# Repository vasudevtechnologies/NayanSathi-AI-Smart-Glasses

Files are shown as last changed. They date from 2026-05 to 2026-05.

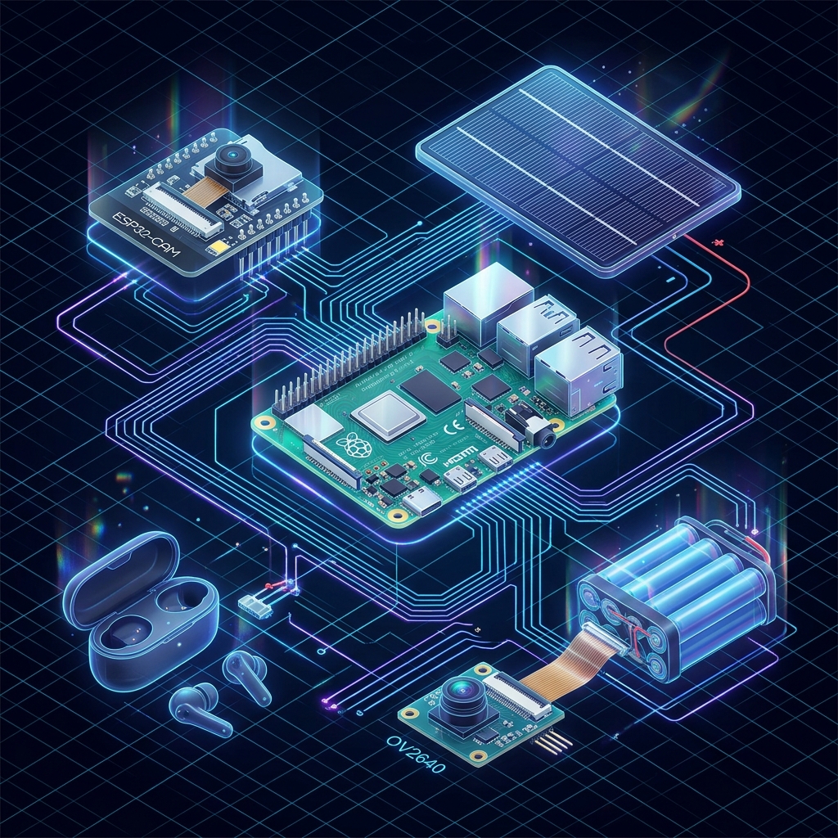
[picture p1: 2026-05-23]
website/images/hardware-diagram.png

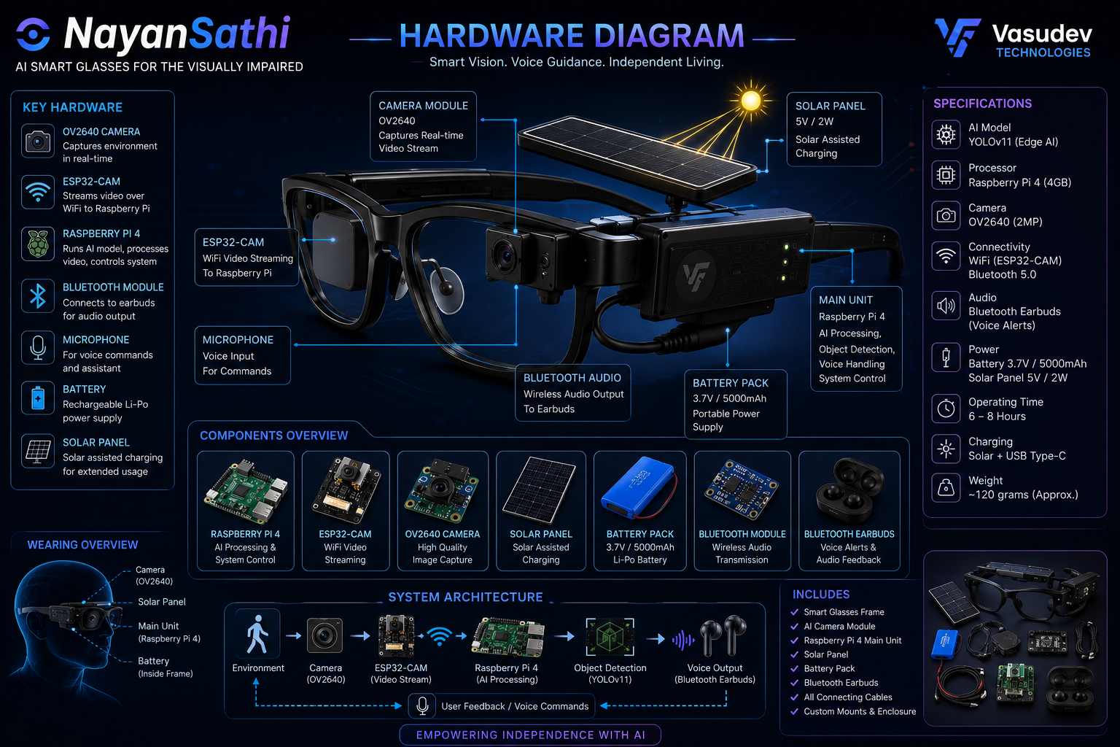
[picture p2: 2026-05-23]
Hardware/Hardware.png

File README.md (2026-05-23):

# NayanSathi-AI-Smart-Glasses
🕶️ NayanSathi — AI Smart Glasses for the Visually Impaired NayanSathi is an AI-powered wearable assistive system designed to help visually impaired individuals navigate and understand their surroundings in real time. Built using Raspberry Pi 4, ESP32-CAM, YOLOv11, and Edge AI technologies, the smart glasses detect nearby objects

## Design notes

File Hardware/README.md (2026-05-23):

# 🔧 Hardware

This folder contains all hardware-related files for **NayanSathi — AI Smart Glasses**.

## Contents
- Component datasheets (Raspberry Pi 4, ESP32-CAM, TP4056, etc.)
- Wiring diagrams
- 3D model files for glasses frame (.stl, .step)
- Bill of Materials (BOM)
- Assembly instructions
- Solar panel integration guide

## Bill of Materials (BOM)

| Component | Model | Specification | Cost (INR) |
|---|---|---|---|
| Raspberry Pi 4 | 4GB RAM | Quad-core ARM Cortex-A72 | Rs. 5,500 |
| ESP32-CAM | OV2640 | 2MP, Wi-Fi, MJPEG stream | Rs. 350 |
| Bluetooth Earbuds | boAt Airdopes 141 | A2DP, Bluetooth 5.0 | Rs. 700 |
| Li-Po Battery | 3000mAh 3.7V | Rechargeable, compact | Rs. 450 |
| Solar Panel | 5V / 1W Flexible | Magnetic clip-on design | Rs. 350 |
| TP4056 Module | Charge Controller | Overcharge protection | Rs. 30 |
| MT3608 Boost | 5V Boost Converter | 3.7V to 5V | Rs. 50 |
| 3D Printed Frame | Custom Design | PLA, glasses form factor | Rs. 400 |
| Custom PCB | KiCad Designed | ESP32 + Power circuit | Rs. 200 |
| MicroSD Card | 32GB Class 10 | OS + model storage | Rs. 200 |
| Misc (wires, etc.) | — | Jumper wires, resistors | Rs. 100 |
| **TOTAL** | | | **~Rs. 8,330** |

## Solar Panel Design
- **Attachment:** Magnetic pogo-pin connectors on glasses top bar
- **Daytime:** Snap-on → charges Li-Po via TP4056 (~100–200mA)
- **Nighttime:** Snap-off in 1 second — lightweight, no tools needed
- **Added weight:** ~20g when attached

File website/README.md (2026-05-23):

# NayanSathi — Website Deployment Guide

> 🚀 Futuristic AI Startup showcase website for NayanSathi

## 📁 Folder Structure

```
website/
├── index.html          ← Main website (all CSS + JS embedded)
├── vercel.json         ← Vercel deployment config
├── images/
│   ├── hero.png                ← AI Smart Glasses hero image (exploded view)
│   ├── product-showcase.png    ← Product showcase with key specs
│   ├── hardware-diagram.png    ← Full hardware diagram
│   ├── circuit-diagram.png     ← Complete circuit/wiring diagram
│   └── day-night.png           ← Day & Night mode comparison
└── README.md
```

## 🖼️ Adding Your Images

Copy your 5 project images into the `images/` folder with EXACTLY these filenames:

| Filename | Description |
|---|---|
| `hero.png` | The NayanSathi AI glasses exploded holographic render |
| `product-showcase.png` | Product showcase with specs on the right |
| `hardware-diagram.png` | Full hardware component diagram |
| `circuit-diagram.png` | Complete circuit / wiring diagram |
| `day-night.png` | Day mode vs Night mode comparison |

## 🌐 Deploy to Vercel

### Method 1: Vercel CLI (Recommended)
```bash
# Install Vercel CLI
npm install -g vercel

# Navigate to website folder
cd website/

# Deploy
vercel --prod
```

### Method 2: Vercel Dashboard (Easiest)
1. Go to [vercel.com](https://vercel.com)
2. Click **Add New → Project**
3. Import from GitHub: `vasudevtechnologies/NayanSathi-AI-Smart-Glasses`
4. Set **Root Directory** to `website`
5. Click **Deploy** ✅

### Method 3: Drag & Drop
1. Go to [vercel.com/new](https://vercel.com/new)
2. Drag the entire `website/` folder into Vercel
3. Done!

## ✅ Website Sections

- 🎬 **Hero** — Cinematic hero with live HUD stats
- ✨ **Features** — 9 feature cards with glow hover effects
- 🖼️ **Product Showcase** — Full-width product image + specs
- 🔄 **System Architecture** — Animated flow diagram
- 🔧 **Hardware Diagram** — Your actual hardware image
- 📊 **Live Dashboard** — Animated fake dashboard with canvas cam feed
- 🌙 **Day/Night Mode** — Power system showcase
- ⚡ **Circuit Diagram** — Full wiring schematic  
- 🔮 **Future Scope** — 6 roadmap cards
- 🏢 **About** — Vasudev Technologies branding
- 🦶 **Footer** — Links, social, copyright

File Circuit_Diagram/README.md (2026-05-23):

# ⚡ Circuit_Diagram

This folder contains all circuit schematics and PCB design files for **NayanSathi — AI Smart Glasses**.

## Contents
- `esp32_multi_sensor.kicad_pcb` — Main KiCad PCB design
- `schematic.pdf` — Printable full circuit schematic
- `wiring_diagram.png` — Complete wiring connection diagram
- `power_circuit.png` — Solar + battery power circuit
- `pcb_gerber/` — Gerber files for PCB manufacturing

## Power Circuit

```
☀️ Solar Panel (5V, 1W)
         │
         ▼
   ┌─────────────┐
   │   TP4056    │  ← Charge Controller (overcharge protected)
   │   Module    │
   └──────┬──────┘
          │
          ▼
   Li-Po Battery (3.7V, 3000mAh)
          │
          ▼
   ┌─────────────┐
   │   MT3608    │  ← Boost Converter (3.7V → 5V)
   │   Boost     │
   └──────┬──────┘
          │
     ┌────┴────┐
     ▼         ▼
Raspberry Pi 4  ESP32-CAM
  (USB-C 5V)   (5V Pin)
```

## Pin Connections

| From | Pin | To | Pin | Signal |
|---|---|---|---|---|
| ESP32-CAM | GPIO 1 (TX) | Raspberry Pi | GPIO 15 (RX) | UART |
| ESP32-CAM | 5V | MT3608 OUT | 5V | Power |
| ESP32-CAM | GND | Common GND | GND | Ground |
| Solar Panel | + | TP4056 | IN+ | 5V Solar Input |
| Solar Panel | - | TP4056 | IN- | Ground |
| TP4056 | BAT+ | Li-Po | + | Battery Charge |
| Li-Po | + | MT3608 | IN+ | 3.7V Input |
| MT3608 | OUT+ | Pi USB-C | + | 5V Output |
| Voltage Divider | OUT | Pi | GPIO ADC | Battery % |

## PCB Features (KiCad Design)
- ESP32-CAM mounting pads with castellated holes
- TP4056 solar charge controller footprint
- MT3608 boost converter section
- Voltage divider circuit (100kΩ + 100kΩ) for battery ADC monitoring
- I2C header (SDA/SCL) for optional IMU / barometer sensor
- Push button (GPIO 17) for mode switching
- 3x LED indicators: Power (Green), Bluetooth (Blue), Detection (Cyan)
- Magnetic pogo-pin pads for solar panel connector

## PCB Dimensions
- Size: ~45mm × 30mm (fits inside glasses frame)
- Layers: 2-layer PCB
- Thickness: 1.6mm standard FR4

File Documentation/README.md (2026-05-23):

# 📄 Documentation

This folder contains all project documentation for **NayanSathi — AI Smart Glasses**.

## Contents
- `Project_Report.pdf` — Full technical report
- `Abstract.pdf` — One-page project abstract
- `Presentation.pptx` — Slide deck for evaluation
- `User_Manual.pdf` — How to use the glasses
- `API_Docs.md` — REST API and WebSocket documentation
- `References.md` — Research papers and citations

## Project Abstract

**NayanSathi** ("Eye Companion") is an AI-powered wearable assistive device built as smart glasses for visually impaired individuals. Using a Raspberry Pi 4 + ESP32-CAM + YOLOv11n ONNX model, it provides real-time object detection with natural voice announcements delivered through Bluetooth earbuds via Piper TTS engine.

The system includes a full web dashboard for remote monitoring and control via SSH, a multi-layer camera fallback system, and an attachable solar panel using magnetic pogo-pin connectors for extended battery life.

## Key Specifications

| Specification | Value |
|---|---|
| Total Cost | ~Rs. 8,280 (~$100 USD) |
| Detection Speed | 8–15 FPS on Raspberry Pi 4 CPU |
| Voice Latency | ~800ms–1.2s end-to-end |
| Battery Life | 2.5–5 hours (3–5 with solar) |
| Object Classes | 80 COCO classes |
| Model Size | ~10.9 MB (YOLOv11 Nano) |
| Audio | Bluetooth A2DP (Piper TTS) |
| Remote Access | SSH + WebSocket + Cloudflare Tunnel |

## Comparison with Commercial Products

| Feature | NayanSathi | OrCam MyEye |
|---|---|---|
| Cost | Rs. 8,280 (~$100) | Rs. 2.9 lakh (~$3,500) |
| Open Source | Yes | No |
| Customizable | Yes (retrain model) | No |
| Solar Panel | Yes | No |
| Web Dashboard | Yes | No |
| Internet Remote | Yes | No |
| Edge AI | Yes | Yes |

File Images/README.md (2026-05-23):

# 📸 Images

This folder contains all project images for **NayanSathi — AI Smart Glasses**.

## Contents
- Project prototype photos (hardware assembly, wearable device)
- Dashboard screenshots
- YOLO detection result screenshots (bounding boxes)
- Team and demo event photos
- Poster and banner images

## Naming Convention
```
nayansathi_prototype_v1.jpg
dashboard_screenshot_01.png
yolo_detection_sample.png
hardware_assembly.jpg
solar_panel_attach.jpg
```

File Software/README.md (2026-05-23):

# 💻 Software

This folder contains all software source files for **NayanSathi — AI Smart Glasses**.

## Folder Structure
```
Software/
├── pi_scripts/
│   ├── nayansathi.py        # Main Pi orchestration script
│   ├── yolo_server.py       # YOLOv11 ONNX inference + WebSocket (port 8765)
│   ├── pi_voice_server.py   # Piper TTS HTTP server (port 3001)
│   ├── setup.sh             # Pi environment setup script
│   └── install_yolo.sh      # ONNX Runtime + dependencies installer
├── server/
│   ├── server.js            # Node.js backend (REST + WebSocket + SSH proxy)
│   └── package.json         # Node.js dependencies
├── esp32/
│   └── esp32cam_uart.ino    # Arduino firmware for ESP32-CAM
└── dashboard/
    ├── index.html           # Main dashboard UI
    └── bt_voice.html        # Bluetooth voice control panel
```

## Tech Stack
| Layer | Technology |
|---|---|
| AI Inference | Python + ONNX Runtime |
| Voice Output | Piper TTS (Indian English) |
| Backend Server | Node.js + Express + WebSocket |
| Frontend | HTML + CSS + JavaScript |
| Camera Firmware | Arduino C++ (ESP32-CAM) |
| SSH Terminal | xterm.js |
| Browser Detection | TensorFlow.js COCO-SSD |

## Quick Start
```bash
# 1. On Raspberry Pi
pip install onnxruntime piper-tts opencv-python websockets
python yolo_server.py &
python pi_voice_server.py &

# 2. On Laptop/PC
npm install
node server.js

# 3. Open browser
# http://localhost:3000
```

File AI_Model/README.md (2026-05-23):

# 🤖 AI_Model

This folder contains all AI/ML model files for **NayanSathi — AI Smart Glasses**.

## Primary Model: YOLOv11n (ONNX)

| Property | Detail |
|---|---|
| File | `yolo11n.onnx` |
| Size | ~10.9 MB |
| Format | ONNX (Open Neural Network Exchange) |
| Framework | Ultralytics YOLOv11 → ONNX Runtime |
| Input Size | 640 × 640 pixels |
| Classes | 80 COCO classes |
| Inference | ONNX Runtime on Raspberry Pi 4 ARM CPU |
| Speed | 8–15 FPS on Pi 4 (CPU only) |
| Confidence | 0.55 default threshold (tunable per class) |

## Training Pipeline

```
Step 1 ── Dataset
         COCO 2017: 118,000 images, 80 pre-labeled classes

Step 2 ── Base Model
         Download: yolo11n.pt (Ultralytics pretrained on COCO)

Step 3 ── Fine-Tuning (custom objects)
         Label: Roboflow or LabelImg
         Train: python train.py --model yolo11n.pt --data custom.yaml --epochs 50
         GPU:   Google Colab T4 (free, ~1 hour for 50 epochs)

Step 4 ── Export to ONNX
         from ultralytics import YOLO
         model = YOLO('yolo11n.pt')
         model.export(format='onnx', imgsz=640, simplify=True)

Step 5 ── Deploy to Pi
         SFTP yolo11n.onnx → /home/pi/NayanSathi/
         pip install onnxruntime
         python yolo_server.py
```

## 80 COCO Classes Detected
person, bicycle, car, motorcycle, airplane, bus, train, truck, boat, traffic light, fire hydrant, stop sign, parking meter, bench, bird, cat, dog, horse, sheep, cow, elephant, bear, zebra, giraffe, backpack, umbrella, handbag, tie, suitcase, frisbee, skis, snowboard, sports ball, kite, baseball bat, baseball glove, skateboard, surfboard, tennis racket, bottle, wine glass, cup, fork, knife, spoon, bowl, banana, apple, sandwich, orange, broccoli, carrot, hot dog, pizza, donut, cake, chair, couch, potted plant, bed, dining table, toilet, tv, laptop, mouse, remote, keyboard, cell phone, microwave, oven, toaster, sink, refrigerator, book, clock, vase, scissors, teddy bear, hair drier, toothbrush

## Other Models in System

| Model | Purpose | Framework | Status |
|---|---|---|---|
| TF.js COCO-SSD | Browser webcam fallback | TensorFlow.js | Active |
| XGBoost | Anomaly / theft detection | scikit-learn | Active |
| MobileNet SSD | Lightweight Pi backup | TF Lite | Planned |
| Whisper (tiny) | Voice command input | OpenAI Whisper | Planned |
| DepthAnything | Monocular depth estimation | PyTorch | Planned |
| DeepFace/FaceNet | Face recognition | TF / OpenCV | Planned |
| EasyOCR | Text/sign/currency reading | PyTorch | Planned |

## Voice Priority System
```python
PRIORITY = {
    'person': 10,  # Always announce first
    'car': 8, 'truck': 8, 'bus': 8,
    'motorcycle': 7, 'bicycle': 7,
    'dog': 6, 'cat': 6,
    'phone': 5,
    'bottle': 3, 'cup': 3
}
COOLDOWN = 6000  # ms — no repeat within 6 seconds per class
```

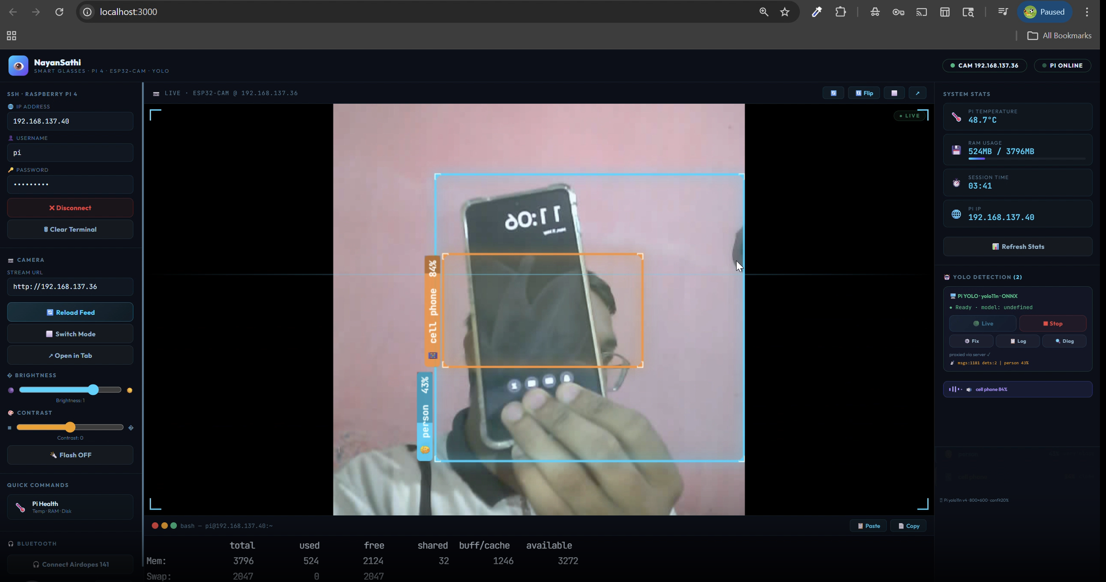
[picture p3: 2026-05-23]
Images/yolo-detection-phone+person-demo.png

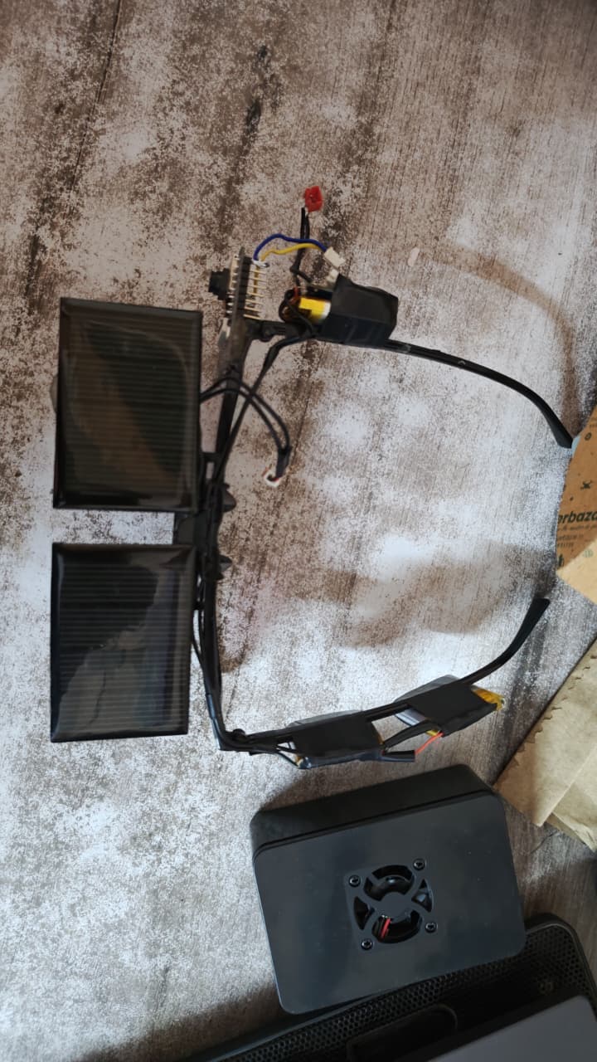
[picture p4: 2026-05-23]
Images/smart-glasses-with-solar-top-view.png

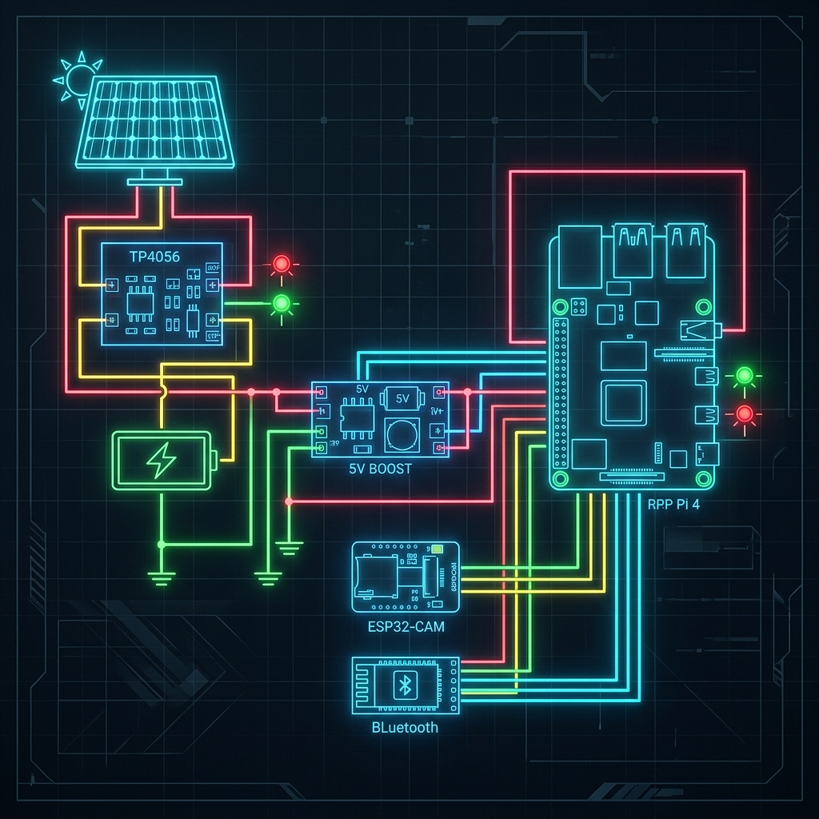
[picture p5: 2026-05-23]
website/images/circuit-diagram.png

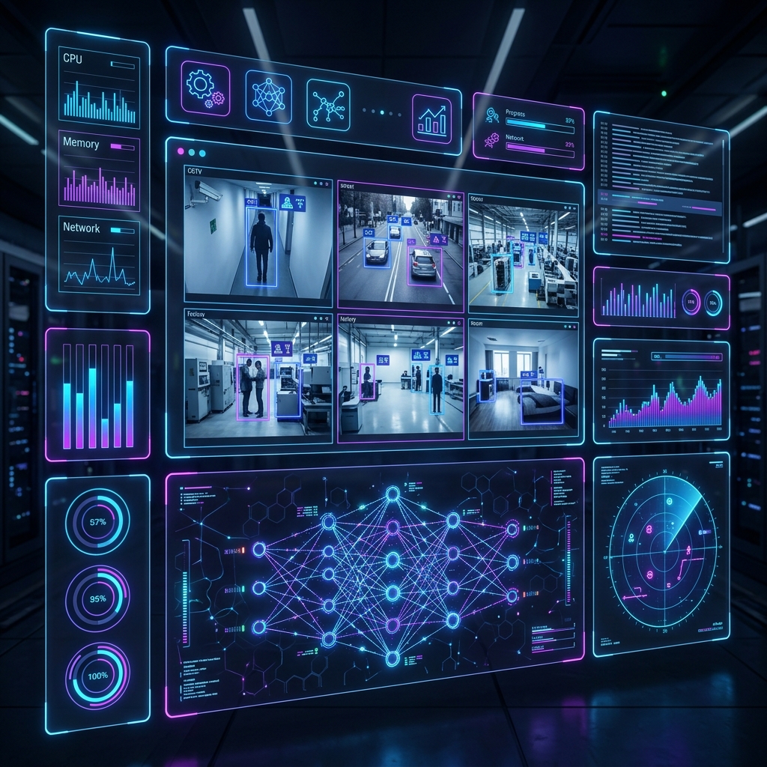
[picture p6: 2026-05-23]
website/images/dashboard.png

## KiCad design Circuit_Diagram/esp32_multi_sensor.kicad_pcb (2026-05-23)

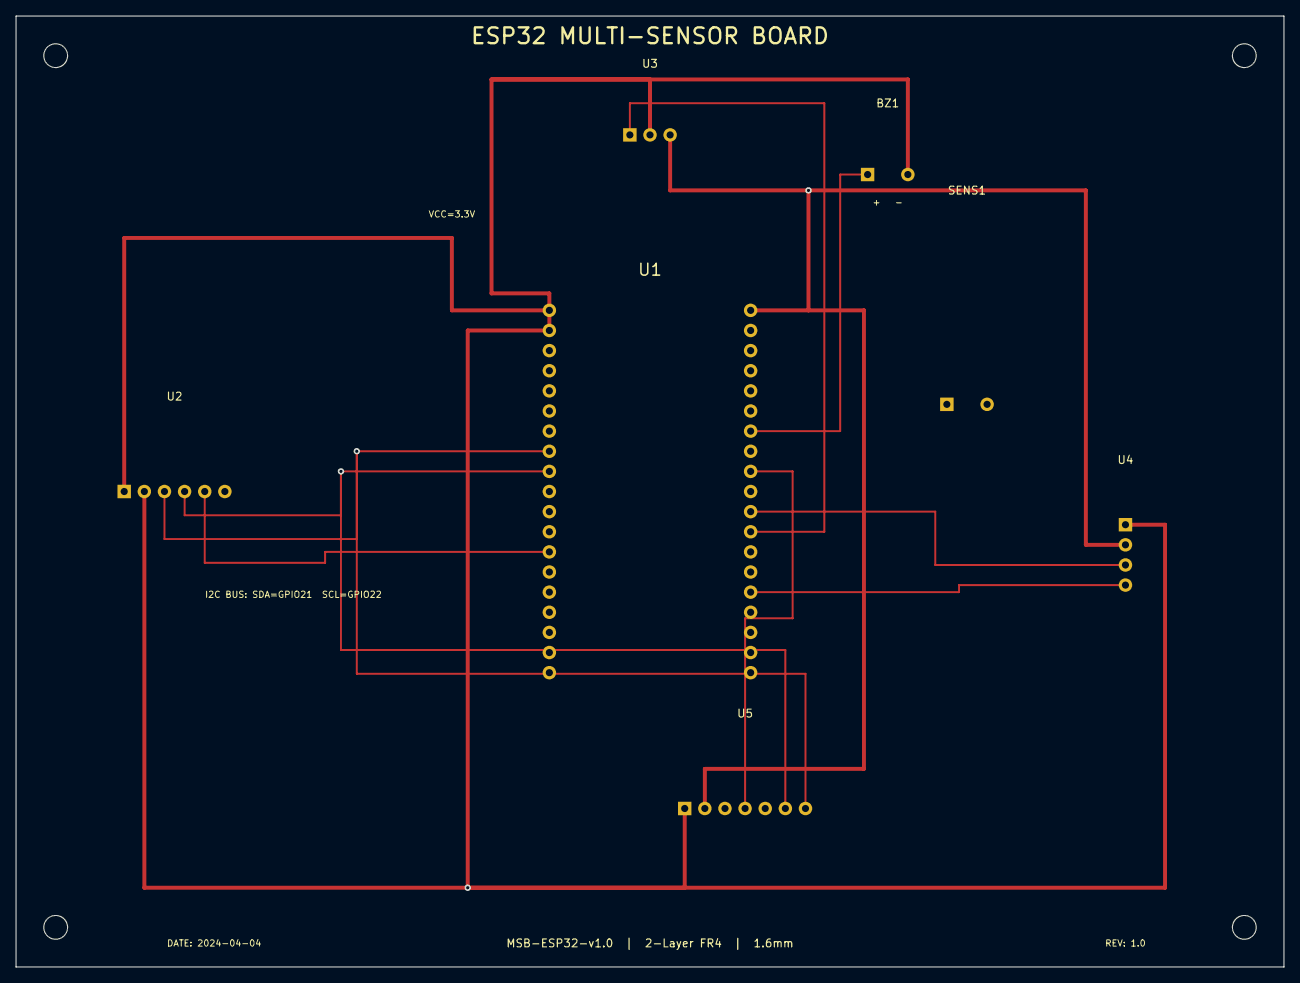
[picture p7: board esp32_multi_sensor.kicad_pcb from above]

Board: 2 copper layers, 160.0 x 120.0 mm, 7 parts (0 on the bottom side), 10 nets.

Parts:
BZ1: Buzzer-5V; Buzzer_12mm_Vertical
SENS1: Rain-Pad; RainPad
U1: NodeMCU-32S
U2: CJVL53L0XV2; VL53L0X_Module
U3: IR-Sensor; IR_Module_3P
U4: Rain-LM393; RainModule_LM393
U5: ADXL345; ADXL345_Module

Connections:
ADXL_INT1: U1.R9, U5.4
BUZZER_OUT: BZ1.1, U1.R7
GND: BZ1.2, U1.L2, U1.L18, U1.R2, U1.R16, U2.2, U3.2, U4.1, U5.1
I2C_SCL: U1.L8, U2.3, U5.7
I2C_SDA: U1.L9, U2.4, U5.6
IR_OUT: U1.R12, U3.1
RAIN_AO: U1.R15, U4.4
RAIN_DO: U1.R11, U4.3
VCC_3V3: U1.L1, U1.L19, U1.R1, U1.R17, U2.1, U3.3, U4.2, U5.2
XSHUT: U1.L13, U2.5

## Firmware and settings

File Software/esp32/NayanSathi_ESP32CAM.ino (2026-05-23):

/*
 ╔══════════════════════════════════════════════════════════════╗
 ║  NayanSathi ESP32-CAM  ·  Multi-Client Stable Streaming     ║
 ║  v3 — Browser + Pi YOLO simultaneous, no crash, no lag      ║
 ╠══════════════════════════════════════════════════════════════╣
 ║  WIRING:                                                     ║
 ║    5V power  → ESP32-CAM 5V  (MUST be 5V/500mA+)           ║
 ║    GND       → ESP32-CAM GND                                ║
 ║    Programmer TX → U0R   (for flashing only)                ║
 ║    Programmer RX → U0T   (for flashing only)                ║
 ║    IO0 → GND during flash, REMOVE for run                   ║
 ║                                                             ║
 ║  ENDPOINTS:                                                 ║
 ║    http://192.168.1.36:81/stream   ← browser dashboard      ║
 ║    http://192.168.1.36:82/stream   ← Raspberry Pi YOLO      ║
 ║    http://192.168.1.36/snap        ← single JPEG snapshot   ║
 ║    http://192.168.1.36/status      ← JSON status            ║
 ║    http://192.168.1.36/control     ← camera settings        ║
 ╚══════════════════════════════════════════════════════════════╝
*/

#include "esp_camera.h"
#include <WiFi.h>
#include <HTTPClient.h>
#include "esp_http_server.h"
#include "freertos/semphr.h"

// ═══════════════════════════════════════════════════════════════
// CONFIGURATION  — edit these
// ═══════════════════════════════════════════════════════════════
const char* SSID = "Thakre";
const char* PASS = "KRISHNA2277";

IPAddress IP (192,168,1,36);   // ESP32-CAM static IP
IPAddress GW (192,168,1, 1);   // Router gateway
IPAddress SN (255,255,255,0);  // Subnet mask

const char* PI_SERVER = "http://192.168.1.33:3000/api/cam-register";


// ═══════════════════════════════════════════════════════════════
// AI-THINKER PIN MAP (do not change)
// ═══════════════════════════════════════════════════════════════
#define PWDN  32
#define RESET -1
#define XCLK   0
#define SDA   26
#define SCL   27
#define D7    35
#define D6    34
#define D5    39
#define D4    36
#define D3    21
#define D2    19
#define D1    18
#define D0     5
#define VSYNC 25
#define HREF  23
#define PCLK  22
#define LED    4   // Flash LED

// ═══════════════════════════════════════════════════════════════
// MJPEG STREAM CONSTANTS
// ═══════════════════════════════════════════════════════════════
#define BOUNDARY  "gc0p4Jq0M2Yt08jU534c0p"
static const char* CT    = "multipart/x-mixed-replace;boundary=" BOUNDARY;
static const char* BOUND = "\r\n--" BOUNDARY "\r\n";
static const char* PART  = "Content-Type: image/jpeg\r\nContent-Length: %u\r\n\r\n";

// HTTP server handles
static httpd_handle_t stream_server1 = NULL;  // port 81 — browser
static httpd_handle_t stream_server2 = NULL;  // port 82 — Pi YOLO
static httpd_handle_t ctrl_server    = NULL;  // port 80 — control

// Frame access semaphore (prevents torn reads)
SemaphoreHandle_t fb_mutex;

// ═══════════════════════════════════════════════════════════════
// SHARED STREAM HANDLER  (used by both port 81 and port 82)
// Each runs in its OWN httpd task — truly parallel!
// ═══════════════════════════════════════════════════════════════
static esp_err_t stream_handler(httpd_req_t* req) {
    char buf[64];
    esp_err_t res;

    httpd_resp_set_type(req, CT);
    httpd_resp_set_hdr(req, "Access-Control-Allow-Origin", "*");
    httpd_resp_set_hdr(req, "Cache-Control", "no-cache, no-store, must-revalidate");
    httpd_resp_set_hdr(req, "X-Source", "NayanSathi-ESP32CAM");

    uint32_t last_frame_ms = 0;
    const uint32_t MIN_FRAME_MS = 66;  // ~15fps max per client

    while (true) {
        // Rate-limit per client
        uint32_t now = millis();
        if (now - last_frame_ms < MIN_FRAME_MS) {
            vTaskDelay(pdMS_TO_TICKS(5));
            continue;
        }

        // Grab frame (with mutex to avoid PSRAM conflicts)
        if (xSemaphoreTake(fb_mutex, pdMS_TO_TICKS(200)) != pdTRUE) continue;
        camera_fb_t* fb = esp_camera_fb_get();
        xSemaphoreGive(fb_mutex);

        if (!fb) {
            vTaskDelay(pdMS_TO_TICKS(20));
            continue;
        }

        last_frame_ms = millis();

        // Boundary
        res = httpd_resp_send_chunk(req, BOUND, strlen(BOUND));
        if (res != ESP_OK) { esp_camera_fb_return(fb); break; }

        // Part header
        int hlen = snprintf(buf, sizeof(buf), PART, fb->len);
        res = httpd_resp_send_chunk(req, buf, hlen);
        if (res != ESP_OK) { esp_camera_fb_return(fb); break; }

        // JPEG data
        res = httpd_resp_send_chunk(req, (const char*)fb->buf, fb->len);
        esp_camera_fb_return(fb);
        if (res != ESP_OK) break;
    }

    httpd_resp_send_chunk(req, NULL, 0);  // end
    return ESP_OK;
}

// ── Snapshot ──────────────────────────────────────────────────
static esp_err_t snap_handler(httpd_req_t* req) {
    if (xSemaphoreTake(fb_mutex, pdMS_TO_TICKS(300)) != pdTRUE) {
        httpd_resp_send_500(req); return ESP_FAIL;
    }
    camera_fb_t* fb = esp_camera_fb_get();
    xSemaphoreGive(fb_mutex);
    if (!fb) { httpd_resp_send_500(req); return ESP_FAIL; }
    httpd_resp_set_type(req, "image/jpeg");
    httpd_resp_set_hdr(req, "Access-Control-Allow-Origin", "*");
    httpd_resp_set_hdr(req, "Cache-Control", "no-cache");
    httpd_resp_send(req, (const char*)fb->buf, fb->len);
    esp_camera_fb_return(fb);
    return ESP_OK;
}

// ── Control endpoint ──────────────────────────────────────────
static esp_err_t ctrl_handler(httpd_req_t* req) {
    char buf[128], k[32], v[16];
    httpd_req_get_url_query_str(req, buf, sizeof(buf));
    httpd_query_key_value(buf, "var", k, sizeof(k));
    httpd_query_key_value(buf, "val", v, sizeof(v));
    int val = atoi(v);
    sensor_t* s = esp_camera_sensor_get();
    if      (!strcmp(k,"framesize"))  s->set_framesize(s,(framesize_t)val);
    else if (!strcmp(k,"quality"))    s->set_quality(s,val);
    else if (!strcmp(k,"brightness")) s->set_brightness(s,val);
    else if (!strcmp(k,"contrast"))   s->set_contrast(s,val);
    else if (!strcmp(k,"saturation")) s->set_saturation(s,val);
    else if (!strcmp(k,"hmirror"))    s->set_hmirror(s,val);
    else if (!strcmp(k,"vflip"))      s->set_vflip(s,val);
    else if (!strcmp(k,"flash"))      digitalWrite(LED,val?HIGH:LOW);
    httpd_resp_set_hdr(req,"Access-Control-Allow-Origin","*");
    httpd_resp_sendstr(req,"OK");
    return ESP_OK;
}

// ── Status JSON ───────────────────────────────────────────────
static esp_err_t status_handler(httpd_req_t* req) {
    sensor_t* s = esp_camera_sensor_get();
    char json[400];
    snprintf(json, sizeof(json),
        "{\"ip\":\"%s\","
        "\"browser_stream\":\"http://%s:81/stream\","
        "\"pi_stream\":\"http://%s:82/stream\","
        "\"snap\":\"http://%s/snap\","
        "\"framesize\":%d,\"quality\":%d,"
        "\"psram\":%s,\"free_heap\":%lu}",
        WiFi.localIP().toString().c_str(),
        WiFi.localIP().toString().c_str(),
        WiFi.localIP().toString().c_str(),
        WiFi.localIP().toString().c_str(),
        s->status.framesize, s->status.quality,
        psramFound()?"true":"false",
        esp_get_free_heap_size());
    httpd_resp_set_type(req,"application/json");
    httpd_resp_set_hdr(req,"Access-Control-Allow-Origin","*");
    httpd_resp_send(req,json,strlen(json));
    return ESP_OK;
}

// ═══════════════════════════════════════════════════════════════
// SERVER STARTUP FUNCTIONS
// ═══════════════════════════════════════════════════════════════

void startStream(uint16_t port, httpd_handle_t* handle) {
    if (*handle) { httpd_stop(*handle); *handle = NULL; delay(100); }

    httpd_config_t cfg       = HTTPD_DEFAULT_CONFIG();
    cfg.server_port          = port;
    cfg.ctrl_port            = (port == 81) ? 32768 : 32769;
    cfg.stack_size           = 8192;           // larger stack for streaming
    cfg.max_uri_handlers     = 4;
    cfg.max_resp_headers     = 8;
    cfg.backlog_conn         = 2;              // queue max 2 pending
    cfg.lru_purge_enable     = true;           // auto-close idle slots
    cfg.recv_wait_timeout    = 5;
    cfg.send_wait_timeout    = 10;

    httpd_uri_t uri = {"/stream", HTTP_GET, stream_handler, NULL};

    if (httpd_start(handle, &cfg) == ESP_OK) {
        httpd_register_uri_handler(*handle, &uri);
        Serial.printf("[HTTP] Stream server on port %d ✓\n", port);
    } else {
        Serial.printf("[HTTP] Failed to start port %d\n", port);
    }
}

void startControl() {
    if (ctrl_server) { httpd_stop(ctrl_server); ctrl_server = NULL; delay(100); }

    httpd_config_t cfg    = HTTPD_DEFAULT_CONFIG();
    cfg.server_port       = 80;
    cfg.ctrl_port         = 32770;
    cfg.stack_size        = 4096;
    cfg.max_uri_handlers  = 8;
    cfg.lru_purge_enable  = true;

    httpd_uri_t u_ctrl   = {"/control", HTTP_GET, ctrl_handler,   NULL};
    httpd_uri_t u_snap   = {"/snap",    HTTP_GET, snap_handler,   NULL};
    httpd_uri_t u_status = {"/status",  HTTP_GET, status_handler, NULL};

    if (httpd_start(&ctrl_server, &cfg) == ESP_OK) {
        httpd_register_uri_handler(ctrl_server, &u_ctrl);
        httpd_register_uri_handler(ctrl_server, &u_snap);
        httpd_register_uri_handler(ctrl_server, &u_status);
        Serial.println("[HTTP] Control server on port 80 ✓");
    }
}

// ── LED blink helper ──────────────────────────────────────────
void blink(int n, int ms=150) {
    for (int i=0; i<n; i++) {
        digitalWrite(LED,HIGH); delay(ms);
        digitalWrite(LED,LOW);  delay(ms);
    }
}

// ── Announce to dashboard ─────────────────────────────────────
void announceToServer() {
    String myIP  = WiFi.localIP().toString();
    String mac   = WiFi.macAddress();
    HTTPClient http;
    http.begin(PI_SERVER);
    http.setTimeout(3000);
    http.addHeader("Content-Type","application/json");
    String body = "{\"ip\":\"" + myIP + "\","
                  "\"stream\":\"http://" + myIP + ":81/stream\","
                  "\"pi_stream\":\"http://" + myIP + ":82/stream\","
                  "\"snap\":\"http://" + myIP + "/snap\","
                  "\"mac\":\"" + mac + "\","
                  "\"status\":\"online\"}";
    int code = http.POST(body);
    Serial.printf("[REG] Dashboard response: %d\n", code);
    http.end();
}

// ═══════════════════════════════════════════════════════════════
// SETUP
// ═══════════════════════════════════════════════════════════════
void setup() {
    Serial.begin(115200);
    Serial.println("\n╔══════════════════════════════╗");
    Serial.println("║  NayanSathi ESP32-CAM v3     ║");
    Serial.println("╚══════════════════════════════╝");

    pinMode(LED, OUTPUT);
    digitalWrite(LED, LOW);
    blink(1, 80);

    // Create frame mutex
    fb_mutex = xSemaphoreCreateMutex();

    // ── Camera config ─────────────────────────────────────────
    camera_config_t cfg;
    cfg.ledc_channel = LEDC_CHANNEL_0;
    cfg.ledc_timer   = LEDC_TIMER_0;
    cfg.pin_d0=D0; cfg.pin_d1=D1; cfg.pin_d2=D2; cfg.pin_d3=D3;
    cfg.pin_d4=D4; cfg.pin_d5=D5; cfg.pin_d6=D6; cfg.pin_d7=D7;
    cfg.pin_xclk=XCLK; cfg.pin_pclk=PCLK;
    cfg.pin_vsync=VSYNC; cfg.pin_href=HREF;
    cfg.pin_sscb_sda=SDA; cfg.pin_sscb_scl=SCL;
    cfg.pin_pwdn=PWDN; cfg.pin_reset=RESET;
    cfg.pixel_format = PIXFORMAT_JPEG;
    cfg.grab_mode    = CAMERA_GRAB_LATEST;   // always latest frame, no queue
    cfg.xclk_freq_hz = 20000000;             // 20MHz = faster capture

    if (psramFound()) {
        // PSRAM available — SVGA quality
        cfg.frame_size   = FRAMESIZE_SVGA;   // 800×600
        cfg.jpeg_quality = 12;               // 0=best, 63=worst
        cfg.fb_count     = 2;                // 2 frame buffers
        cfg.fb_location  = CAMERA_FB_IN_PSRAM;
        Serial.println("[CAM] PSRAM found → SVGA 800×600, q=12");
    } else {
        // No PSRAM — use smaller buffer
        cfg.frame_size   = FRAMESIZE_VGA;    // 640×480
        cfg.jpeg_quality = 15;
        cfg.fb_count     = 1;
        cfg.fb_location  = CAMERA_FB_IN_DRAM;
        Serial.println("[CAM] No PSRAM → VGA 640×480, q=15");
    }

    if (esp_camera_init(&cfg) != ESP_OK) {
        Serial.println("[CAM] ❌ INIT FAILED — check 5V power supply!");
        blink(10, 80);
        delay(3000);
        ESP.restart();
    }
    Serial.println("[CAM] ✅ Camera OK");

    // ── Sensor tuning ─────────────────────────────────────────
    sensor_t* s = esp_camera_sensor_get();
    s->set_quality(s, 12);
    s->set_brightness(s, 1);       // +1 brightness (indoor)
    s->set_saturation(s, 0);       // neutral saturation
    s->set_sharpness(s, 1);        // slight sharpening
    s->set_whitebal(s, 1);         // auto white balance ON
    s->set_exposure_ctrl(s, 1);    // auto exposure ON
    s->set_gain_ctrl(s, 1);        // auto gain ON
    s->set_aec2(s, 1);             // AEC2 ON (better exposure)
    s->set_ae_level(s, 0);
    s->set_awb_gain(s, 1);
    s->set_vflip(s, 1);            // camera mounted upside-down
    s->set_hmirror(s, 1);

    // ── WiFi ─────────────────────────────────────────────────
    WiFi.mode(WIFI_STA);
    WiFi.config(IP, GW, SN);
    WiFi.setAutoReconnect(true);
    WiFi.persistent(true);
    WiFi.begin(SSID, PASS);

    Serial.print("[WiFi] Connecting");
    int t = 0;
    while (WiFi.status() != WL_CONNECTED && t++ < 40) {
        delay(500); Serial.print(".");
    }

    if (WiFi.status() != WL_CONNECTED) {
        Serial.println("\n[WiFi] FAILED — restarting in 2s");
        delay(2000); ESP.restart();
    }

    Serial.printf("\n[WiFi] ✅ Connected! IP: %s\n", WiFi.localIP().toString().c_str());
    Serial.printf("[Stream-Browser] http://%s:81/stream\n", WiFi.localIP().toString().c_str());
    Serial.printf("[Stream-Pi]      http://%s:82/stream\n", WiFi.localIP().toString().c_str());
    Serial.printf("[Snap]           http://%s/snap\n",      WiFi.localIP().toString().c_str());

    // ── Start all servers ─────────────────────────────────────
    startStream(81, &stream_server1);   // browser client
    startStream(82, &stream_server2);   // Raspberry Pi YOLO
    startControl();                      // port 80 control/snap/status

    blink(3, 150);  // 3 blinks = all good
    Serial.println("[NayanSathi] ✅ Ready!");

    announceToServer();
}

// ═══════════════════════════════════════════════════════════════
// LOOP — WiFi watchdog only
// ═══════════════════════════════════════════════════════════════
uint32_t last_wifi_check = 0;
uint32_t last_announce   = 0;

void loop() {
    uint32_t now = millis();

    // Check WiFi every 10s (not 5s — reduces interrupt load)
    if (now - last_wifi_check > 10000) {
        last_wifi_check = now;

        if (WiFi.status() != WL_CONNECTED) {
            Serial.println("[WiFi] ⚠️ Lost — reconnecting...");

            WiFi.disconnect(true);
            delay(500);
            WiFi.mode(WIFI_STA);
            WiFi.config(IP, GW, SN);
            WiFi.begin(SSID, PASS);

            int t = 0;
            while (WiFi.status() != WL_CONNECTED && t++ < 20) {
                delay(500); Serial.print(".");
            }

            if (WiFi.status() == WL_CONNECTED) {
                Serial.printf("\n[WiFi] ✅ Reconnected: %s\n",
                              WiFi.localIP().toString().c_str());
                // Restart servers only if needed
                if (!stream_server1) startStream(81, &stream_server1);
                if (!stream_server2) startStream(82, &stream_server2);
                if (!ctrl_server)    startControl();
            } else {
                Serial.println("\n[WiFi] ❌ Failed — restarting");
                delay(1000);
                ESP.restart();
            }
        }

        // Re-announce every 60s (server marks offline after 120s)
        if (WiFi.status() == WL_CONNECTED && now - last_announce > 60000) {
            last_announce = now;
            announceToServer();
        }
    }

    delay(100);  // yield to FreeRTOS tasks
}

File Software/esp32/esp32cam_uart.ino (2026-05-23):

/*
 * NayanSathi — ESP32-CAM UART Frame Streamer
 * Sends JPEG frames directly to Raspberry Pi via UART
 * 
 * Hardware:
 *   ESP32-CAM GPIO1 (TX) → Pi GPIO15 (RXD, Pin 10)
 *   ESP32-CAM GND        → Pi GND
 *   ESP32-CAM 5V         → Pi Pin 2 (5V)
 *
 * Frame Protocol:
 *   [0xAA 0xBB 0xCC 0xDD] [4-byte length LE] [JPEG bytes]
 */

#include "esp_camera.h"

// ── Camera model: AI-Thinker ESP32-CAM ──────────────────────
#define PWDN_GPIO_NUM     32
#define RESET_GPIO_NUM    -1
#define XCLK_GPIO_NUM      0
#define SIOD_GPIO_NUM     26
#define SIOC_GPIO_NUM     27
#define Y9_GPIO_NUM       35
#define Y8_GPIO_NUM       34
#define Y7_GPIO_NUM       39
#define Y6_GPIO_NUM       36
#define Y5_GPIO_NUM       21
#define Y4_GPIO_NUM       19
#define Y3_GPIO_NUM       18
#define Y2_GPIO_NUM        5
#define VSYNC_GPIO_NUM    25
#define HREF_GPIO_NUM     23
#define PCLK_GPIO_NUM     22

// ── Config ───────────────────────────────────────────────────
#define BAUD_RATE     1500000   // 1.5 Mbps — fast but stable on Pi
#define FRAME_MAGIC_1 0xAA
#define FRAME_MAGIC_2 0xBB
#define FRAME_MAGIC_3 0xCC
#define FRAME_MAGIC_4 0xDD
#define TARGET_FPS    8         // target FPS (Pi YOLO will process at its own rate)

// ── LED flash (GPIO4 on AI-Thinker) ─────────────────────────
#define FLASH_LED_PIN 4

void setup() {
  // UART0 to Raspberry Pi
  Serial.begin(BAUD_RATE);
  while (!Serial) delay(10);

  // Flash LED setup
  pinMode(FLASH_LED_PIN, OUTPUT);
  digitalWrite(FLASH_LED_PIN, LOW);

  // Camera config
  camera_config_t config;
  config.ledc_channel = LEDC_CHANNEL_0;
  config.ledc_timer   = LEDC_TIMER_0;
  config.pin_d0       = Y2_GPIO_NUM;
  config.pin_d1       = Y3_GPIO_NUM;
  config.pin_d2       = Y4_GPIO_NUM;
  config.pin_d3       = Y5_GPIO_NUM;
  config.pin_d4       = Y6_GPIO_NUM;
  config.pin_d5       = Y7_GPIO_NUM;
  config.pin_d6       = Y8_GPIO_NUM;
  config.pin_d7       = Y9_GPIO_NUM;
  config.pin_xclk     = XCLK_GPIO_NUM;
  config.pin_pclk     = PCLK_GPIO_NUM;
  config.pin_vsync    = VSYNC_GPIO_NUM;
  config.pin_href     = HREF_GPIO_NUM;
  config.pin_sccb_sda = SIOD_GPIO_NUM;
  config.pin_sccb_scl = SIOC_GPIO_NUM;
  config.pin_pwdn     = PWDN_GPIO_NUM;
  config.pin_reset    = RESET_GPIO_NUM;
  config.xclk_freq_hz = 20000000;
  config.pixel_format = PIXFORMAT_JPEG;
  config.grab_mode    = CAMERA_GRAB_LATEST;  // always grab latest frame
  config.fb_location  = CAMERA_FB_IN_PSRAM;

  // Lower resolution = faster serial transfer + lower latency
  // QVGA(320x240) or CIF(400x296) recommended for UART
  if (psramFound()) {
    config.frame_size   = FRAMESIZE_VGA;   // 640x480
    config.jpeg_quality = 15;              // 0=best, 63=worst
    config.fb_count     = 2;
  } else {
    config.frame_size   = FRAMESIZE_CIF;   // 400x296
    config.jpeg_quality = 20;
    config.fb_count     = 1;
  }

  esp_err_t err = esp_camera_init(&config);
  if (err != ESP_OK) {
    // Signal error via LED blink
    for (int i = 0; i < 10; i++) {
      digitalWrite(FLASH_LED_PIN, HIGH); delay(200);
      digitalWrite(FLASH_LED_PIN, LOW);  delay(200);
    }
    ESP.restart();
  }

  // Optimise sensor settings
  sensor_t *s = esp_camera_sensor_get();
  if (s) {
    s->set_brightness(s, 1);      // slight brightness boost
    s->set_saturation(s, 0);
    s->set_sharpness(s, 1);
    s->set_gainceiling(s, (gainceiling_t)4);
    s->set_awb_gain(s, 1);
    s->set_wb_mode(s, 0);         // auto white balance
    s->set_ae_level(s, 0);
    s->set_aec2(s, 0);
  }

  // Brief flash to signal ready
  digitalWrite(FLASH_LED_PIN, HIGH); delay(100);
  digitalWrite(FLASH_LED_PIN, LOW);
}

void loop() {
  unsigned long t0 = millis();

  camera_fb_t *fb = esp_camera_fb_get();
  if (!fb) {
    delay(50);
    return;
  }

  // Send frame magic header + 4-byte length + JPEG payload
  uint32_t len = fb->len;
  uint8_t header[8];
  header[0] = FRAME_MAGIC_1;
  header[1] = FRAME_MAGIC_2;
  header[2] = FRAME_MAGIC_3;
  header[3] = FRAME_MAGIC_4;
  header[4] = (len      ) & 0xFF;  // length little-endian
  header[5] = (len >>  8) & 0xFF;
  header[6] = (len >> 16) & 0xFF;
  header[7] = (len >> 24) & 0xFF;

  Serial.write(header, 8);
  Serial.write(fb->buf, fb->len);
  Serial.flush();

  esp_camera_fb_return(fb);

  // Throttle to target FPS
  unsigned long elapsed = millis() - t0;
  unsigned long frame_ms = 1000 / TARGET_FPS;
  if (elapsed < frame_ms) delay(frame_ms - elapsed);
}

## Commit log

2026-05-23 Add project folders: Images, Videos, Hardware, Software, Documentation, AI_Model, Circuit_Diagram
2026-05-23 Add all code files for Software (pi_scripts, server, esp32, dashboard), AI_Model (YOLOv11n ONNX), and Circuit_Diagram (KiCad PCB)
    [esp32_multi_sensor.kicad_pcb]
2026-05-23 Add futuristic NayanSathi website for Vercel deployment — includes hero, features, architecture, dashboard, hardware, circuit, future scope sections with AI-generated images
